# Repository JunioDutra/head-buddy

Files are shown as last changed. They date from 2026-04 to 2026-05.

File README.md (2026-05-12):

# 🤖 Desktop Buddy Robot (Raspberry Pi 3)

> Nota de estado atual (2026-04-27): o README abaixo ficou como contexto historico.
> A fonte principal do projeto atual e [AGENTS.md](AGENTS.md), e o redesign em caixa desta sessao esta em [redesign](redesign).
> A imagem [montagem.png](montagem.png) agora reflete esse redesign novo.

Projeto de um robô de mesa minimalista em formato de “cabeça”, projetado para acomodar um Raspberry Pi 3 Model B, uma tela frontal e um powerbank removível, com foco em simplicidade, modularidade e facilidade de montagem.

---

# 🎯 Propósito do Projeto

Este projeto tem como objetivo criar um **robô de mesa funcional e personalizável**, que pode ser utilizado como:

* Assistente local (LLM, automação, dashboards)
* Interface visual com tela frontal
* Dispositivo IoT ou monitoramento
* Objeto decorativo interativo

O design prioriza:

* 🧱 Estrutura simples (fácil de imprimir)
* 🔧 Montagem intuitiva
* 🔋 Manutenção rápida (bateria removível)
* 🧠 Compatibilidade com Raspberry Pi 3 Model B
* 🖥️ Integração com display frontal
* 🧵 Organização interna de cabos

---

# ⚙️ Premissas Técnicas

## 📏 Unidades e Modelagem

* Todas as dimensões são em **milímetros (mm)**
* Escala real **1:1**
* Modelagem feita no **Blender**
* Exportação em **STL**

## 🖨️ Impressão 3D

* Impressora alvo: **Creality Ender 3 V3 SE**
* Material recomendado: **PLA**
* Espessura de parede: **2 a 3 mm**
* Tolerâncias:

  * encaixes: **0.3 a 0.5 mm**
  * partes móveis: **0.5 a 1 mm**

---

# 📦 Componentes Utilizados

## 🧠 Raspberry Pi 3 Model B

* Dimensões: **85 x 56 mm**
* Furos:

  * 58 mm (horizontal)
  * 49 mm (vertical)
  * diâmetro: ~2.7 mm (M2.5)

## 🖥️ Tela

* Tipo: **2.42" OLED I2C** (modelo: 2.420LED-IIC VER:1.1)
* Driver: **SSD1309**
* Referência pública equivalente: **Waveshare 2.42inch OLED Module** para envelope e área visível, não para substituir a furação da placa real
* Resolução: **128 × 64 pixels**
* PCB (módulo): **61.5 × 39.5 mm**
* Área visível do display: **55.01 × 27.49 mm**
* Tamanho do pixel: 0.4 × 0.4 mm
* Interface: **I2C** (4 pinos: VCC, GND, SDA, SCL)
* Tensão: 3.3V / 5V
* Possui:

  * PCB maior que área visível
  * 4 furos circulares de fixação nos cantos da PCB real 2.420LED-IIC VER:1.1
  * a geometria de furação deve seguir a placa real ou foto medida da própria placa
  * não assumir pinos de encaixe como solução de montagem

## 🔋 Powerbank

* Tipo: USB padrão
* Dimensões variáveis (medir manualmente)
* Deve ser **removível facilmente**

---

# 🧱 Arquitetura do Robô

O design segue uma estrutura em camadas:

```
[ FRENTE ]
  → Tela

[ MEIO ]
  → Raspberry Pi

[ FUNDO / BASE ]
  → Powerbank (removível)
```

Benefícios:

* Organização interna
* Melhor ventilação
* Facilidade de montagem
* Acesso rápido à bateria

---

# 🧩 Peças do Projeto

O modelo é dividido nas seguintes partes:

1. Casca externa (estrutura principal)
2. Chassi interno
3. Suporte do Raspberry Pi
4. Suporte da tela
5. Berço do powerbank
6. Tampa traseira
7. Guias de cabos
8. Peça de teste de tolerância

---

# 📁 Estrutura de Saída

Cada peça deve ser exportada como:

```
/stl/
  ├── 01_shell.stl
  ├── 02_internal_chassis.stl
  ├── 03_raspberry_mount.stl
  ├── 04_screen_mount.stl
  ├── 05_powerbank_holder.stl
  ├── 06_back_cover.stl
  ├── 07_cable_guides.stl
  ├── 08_tolerance_test.stl
```

---

# 🧠 Workflow de Desenvolvimento

1. Criar peça no Blender
2. Validar dimensões (painel N)
3. Exportar STL
4. Abrir no slicer (Cura / Prusa)
5. Validar escala
6. Imprimir peça de teste
7. Ajustar tolerâncias
8. Imprimir versão final

---

# ⚠️ Boas Práticas

* Sempre modelar com folga (não justo)
* Nunca confiar “no olho”
* Validar encaixes antes de imprimir tudo
* Priorizar acesso fácil à manutenção
* Planejar cabos desde o início

---

# Imagem da montagem
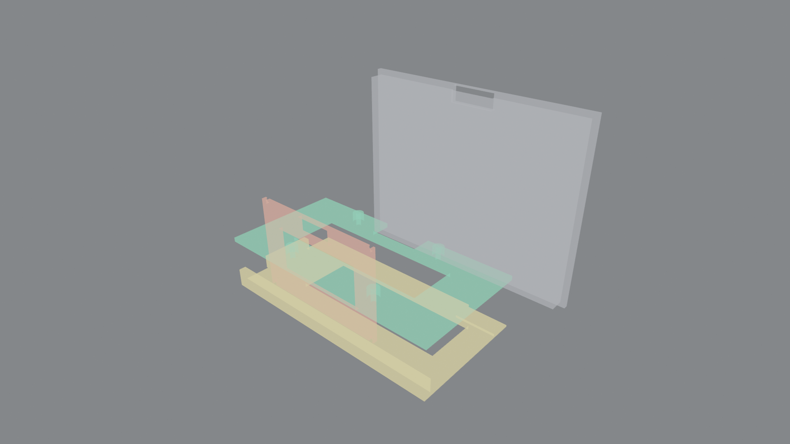
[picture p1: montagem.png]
Imagem do robô montado


---

# 🚀 PROMPTS DE MODELAGEM (ORDEM DE EXECUÇÃO)

## 🔹 0. Prompt Base (usar antes de todos)

```text
Crie uma peça técnica para impressão 3D e também uma imagem ortográfica/industrial do mesmo objeto. 
Use unidades em milímetros, escala real 1:1, precisão mecânica, tolerâncias de impressão 3D e aparência limpa de CAD.
A peça faz parte de um robô de mesa em formato de cabeça quadrada, simples e modular, fácil de montar e desmontar.
Priorize:
- encaixes simples
- manutenção fácil
- passagem organizada de cabos
- fixação segura dos componentes
- paredes com 2 a 3 mm de espessura
- folgas funcionais de 0,3 a 0,5 mm para encaixes impressos em 3D
Não invente proporções artísticas. Respeite medidas reais.
```

---

## 🔹 1. Casca externa

```text
Crie a casca externa de uma cabeça quadrada para robô de mesa, com design minimalista e funcional.

Dimensões externas alvo:
- largura: 120 mm
- altura: 100 mm
- profundidade: 80 mm

Abertura frontal para tela 2.42" OLED:
- abertura: 57 x 29.5 mm (área visível 55x27.5mm + 1mm margem)
- centralizada na frente, a 50mm de altura

Requisitos:
- frente com abertura central para a tela 2.42" OLED
- moldura frontal com espessura visível de 3 a 5 mm
- cantos levemente arredondados (bevel 5mm, 4 segmentos)
- traseira com tampa removível (abertura 110x90mm)
- base estável para ficar sobre mesa
- espaço interno suficiente para Raspberry Pi 3, tela e powerbank
- ventilação discreta nas laterais (5 slots por lado, 2x25mm)
- 4 postes internos de fixação (raio 3mm, altura 5mm)
- manter aparência de “buddy robot”, sem detalhes excessivos

Importante:
- gerar a peça como corpo oco
- prever espessura de parede de 2 a 3 mm
- prever pontos de fixação internos para as demais peças
- não incluir eletrônica modelada, só a estrutura externa
```

---

## 🔹 2. Chassi interno

```text
Crie o chassi interno principal para um robô de mesa em formato de cabeça quadrada.

Função da peça:
- sustentar a tela na frente
- sustentar o Raspberry Pi 3 no meio
- sustentar um powerbank removível na parte traseira ou inferior
- organizar o volume interno em camadas

Requisitos:
- estrutura interna modular
- canais para cabos com pelo menos 5 mm de largura útil
- folga mínima de 1 mm entre componentes e paredes
- divisões internas para separar área da tela, área da placa e área da bateria
- permitir montagem por etapas
- deixar acesso fácil às portas laterais/traseiras do Raspberry
- incluir pontos de apoio para a tampa traseira

Formato:
- peça única ou conjunto simples de suportes interligados
- geometria sólida, sem partes frágeis
- compatível com impressão 3D sem suportes complexos
```

---

## 🔹 3. Suporte Raspberry Pi

```text
Crie um suporte interno específico para Raspberry Pi 3 Model B, em peça separada, com fixação por parafusos.

Medidas obrigatórias da placa:
- placa: 85 mm x 56 mm
- padrão de fixação: 58 mm x 49 mm entre centros dos furos
- cantos da placa com raio aproximado de 3,0 mm
- usar furos de fixação com folga para parafuso M2.5, com diâmetro de passagem em torno de 2,7 mm

Requisitos do suporte:
- 4 standoffs alinhados com os furos oficiais do Raspberry Pi 3 Model B
- altura dos standoffs: 6 mm
- base reforçada para não dobrar
- manter a placa suspensa para passagem de cabos
- deixar as portas USB, Ethernet, HDMI e alimentação acessíveis por uma lateral ou traseira
- tolerância de montagem de 0,3 a 0,5 mm
- bordas arredondadas para facilitar impressão e montagem

Entregue a peça em escala real, pronta para encaixar no interior do robô.
```

---

## 🔹 4. Suporte da tela

```text
Crie a moldura frontal interna e o suporte da tela do robô de mesa.

Tela: 2.42" OLED I2C (SSD1309, 128x64px)
- largura da PCB: 61.5 mm
- altura da PCB: 39.5 mm
- área visível: 55.01 mm x 27.49 mm
- interface: I2C (4 pinos: VCC, GND, SDA, SCL)
- padrão de furos: ~57.5 mm x 35.5 mm (centro a centro)
- diâmetro dos furos: 2.7 mm (M2.5)

Requisitos:
- criar uma janela frontal alinhada exatamente com a área visível
- deixar a PCB da tela escondida atrás da frente
- prever pelo menos 10 mm de espaço atrás da tela para cabo e eletrônica
- incluir 4 pontos de fixação ou um encaixe por pressão controlado
- borda de apoio interna para a tela não cair para a frente
- tolerância de 0,3 a 0,5 mm nos encaixes
- moldura frontal simples, limpa e fácil de imprimir

A peça deve servir tanto como suporte técnico quanto como moldura estética frontal.
```

---

## 🔹 5. Berço do powerbank

```text
Crie um berço removível para prender um powerbank dentro de uma cabeça quadrada de robô de mesa.

Medidas reais do powerbank:
- largura: [LARGURA_POWERBANK] mm
- altura: [ALTURA_POWERBANK] mm
- profundidade: [PROFUNDIDADE_POWERBANK] mm

Requisitos:
- a peça deve permitir remover o powerbank com facilidade, sem desmontar o robô inteiro
- usar encaixe por trilho, berço lateral ou trava simples por pressão
- não usar parafusos no powerbank, para permitir retirada rápida
- deixar folga de 0,5 a 1,0 mm para inserção manual
- prever passagem para cabo de energia sem esmagar o conector
- garantir que o powerbank fique firme durante o uso
- base com apoio plano e lateral com retenção suave
- evitar cantos muito fechados

A peça deve ser simples, robusta e pensada para acesso frequente.
```

---

## 🔹 6. Tampa traseira

```text
Crie a tampa traseira de manutenção para um robô de mesa em formato de cabeça quadrada.

Requisitos:
- abertura fácil para acessar o powerbank, Raspberry Pi e cabos
- fixação simples por snap-fit ou por parafusos M3
- remoção manual sem ferramentas complexas
- encaixe alinhado com a casca externa
- borda de apoio com tolerância de 0,3 a 0,5 mm
- incluir travas ou linguetas suficientes para não abrir sozinha
- manter aparência limpa por fora
- prever ventilação, se necessário, sem comprometer a rigidez

A peça deve ser funcional, discreta e fácil de imprimir.
```

---

## 🔹 7. Guias de cabos

```text
Crie um conjunto de guias internos para cabos dentro de um robô de mesa com Raspberry Pi 3, tela frontal e powerbank removível.

Requisitos:
- canais com largura útil mínima de 5 mm
- curvas suaves, sem dobras apertadas
- separação entre cabos de energia e cabos de sinal quando possível
- clipes ou presilhas opcionais para prender fios
- manter 10 mm de folga atrás da tela
- não bloquear ventilação nem acesso às portas do Raspberry
- guias simples, integradas ao chassi, fáceis de imprimir

A peça deve organizar os fios sem aumentar demais o volume interno.
```

---

## 🔹 8. Peça de teste

```text
Crie uma peça de teste pequena para validar tolerâncias de encaixe antes do modelo final.

Requisitos:
- testar folgas de 0,2 mm, 0,3 mm, 0,4 mm e 0,5 mm
- incluir pequenos encaixes tipo trava, canal e pino
- usar espessura de parede igual à peça final
- servir para validar a impressora e o material
- geometria simples, compacta e rápida de imprimir

A peça deve ajudar a confirmar o ajuste dos encaixes antes de produzir o robô completo.
```

---

# 🧠 Considerações Finais

Este projeto foi pensado para ser:

* Modular
* Iterativo
* Customizável

Não existe uma única versão final — a ideia é evoluir o design conforme testes reais.

---

# � Histórico de Alterações

## v2 — Correção da tela (2.42" OLED I2C)

As peças originais foram modeladas com dimensões de um display 3.5" SPI (PCB 86×56mm).
Após testes de impressão, identificou-se que a tela real é um **2.42" OLED I2C** (PCB 61.5×39.5mm).

Peças reconstruídas:
- **01_shell**: abertura frontal reduzida de 70×50mm para **57×29.5mm**
- **02_internal_chassis**: zona da tela reduzida de 15mm para **12mm** de profundidade
- **04_screen_mount**: totalmente recriado para PCB 61.5×39.5mm, janela 56×28.5mm, slot para cabo I2C, orientação flat para impressão sem suportes. A furação final deve seguir a placa real da OLED 2.420LED-IIC VER:1.1, com **4 furos circulares de canto**

Dimensões confirmadas por referência pública equivalente Waveshare 2.42" OLED Module (SSD1309):
- Módulo: 61.5 × 39.5 mm
- Área visível: 55.01 × 27.49 mm
- Pixel: 0.4 × 0.4 mm
- Resolução: 128 × 64

---

# 💡 Próximos Passos

* Integrar áudio (speaker + mic)
* Criar versão com ventilação ativa
* Evoluir design externo (personalidade do robô)

---

# 👾 Filosofia do Projeto

> Primeiro funcional. Depois bonito. Sempre simples.

---

Boa sorte com o build 🚀

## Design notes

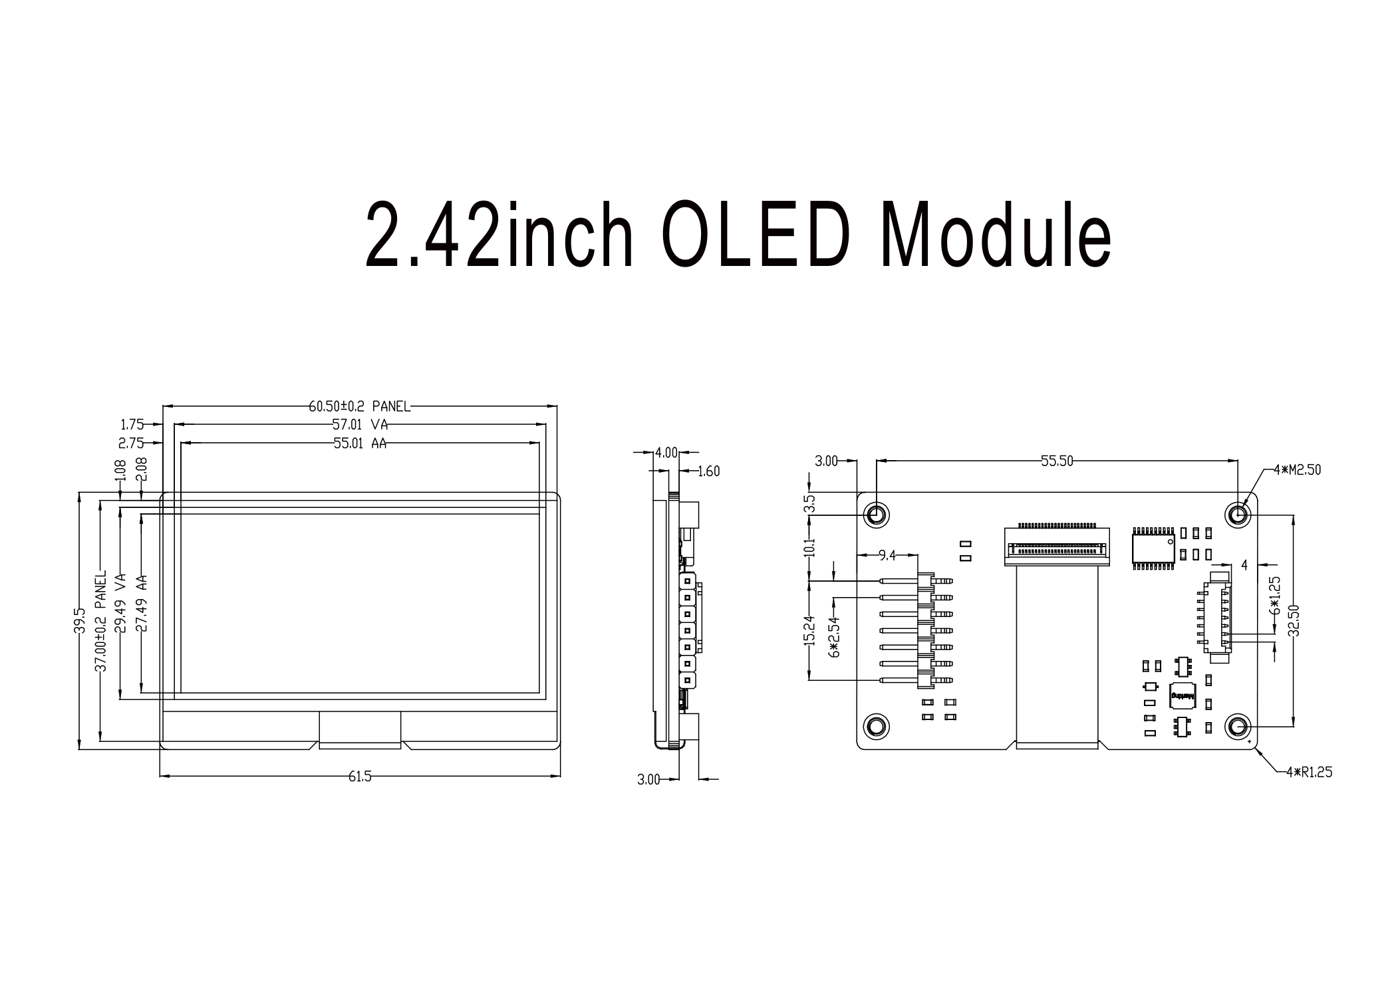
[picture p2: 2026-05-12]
design/tmp_oled_ref_page1.png

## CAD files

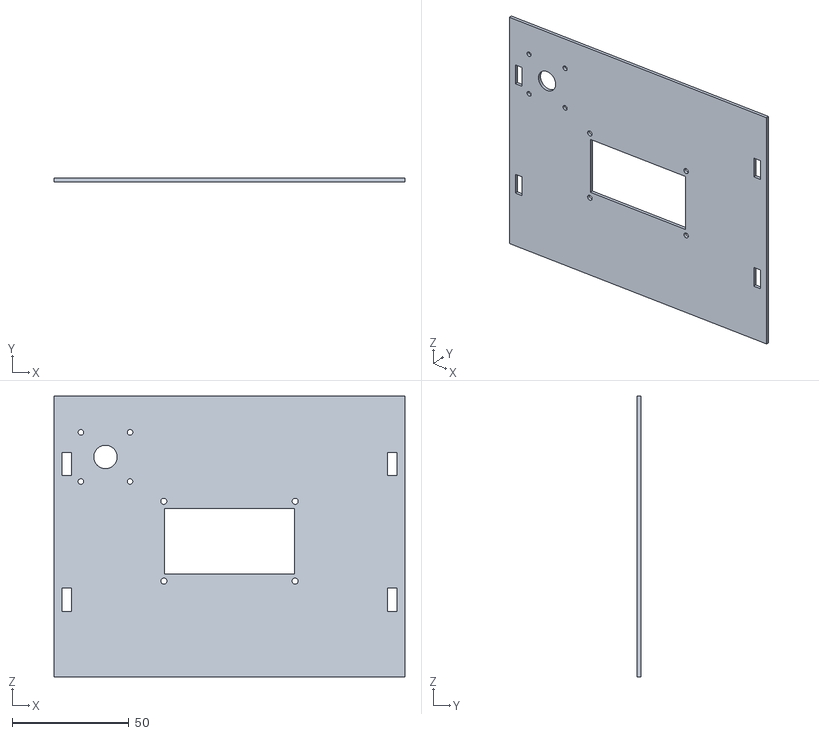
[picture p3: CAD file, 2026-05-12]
design/stl/rd_front_panel_v3.stl
150.0 x 1.50 x 120.0

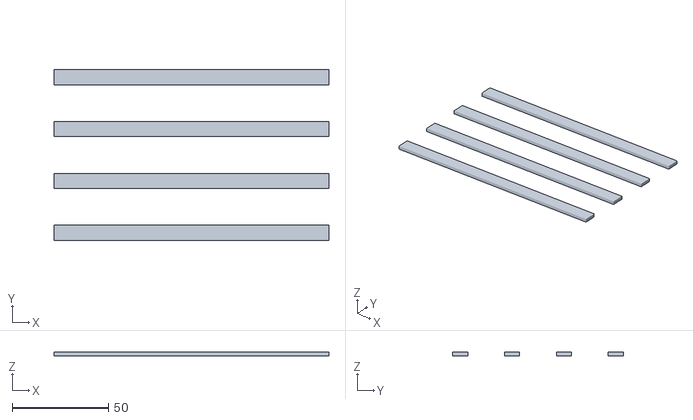
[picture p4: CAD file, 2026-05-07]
design/stl/rd_support_slat_base_v1.stl
143.0 x 89.0 x 2.13

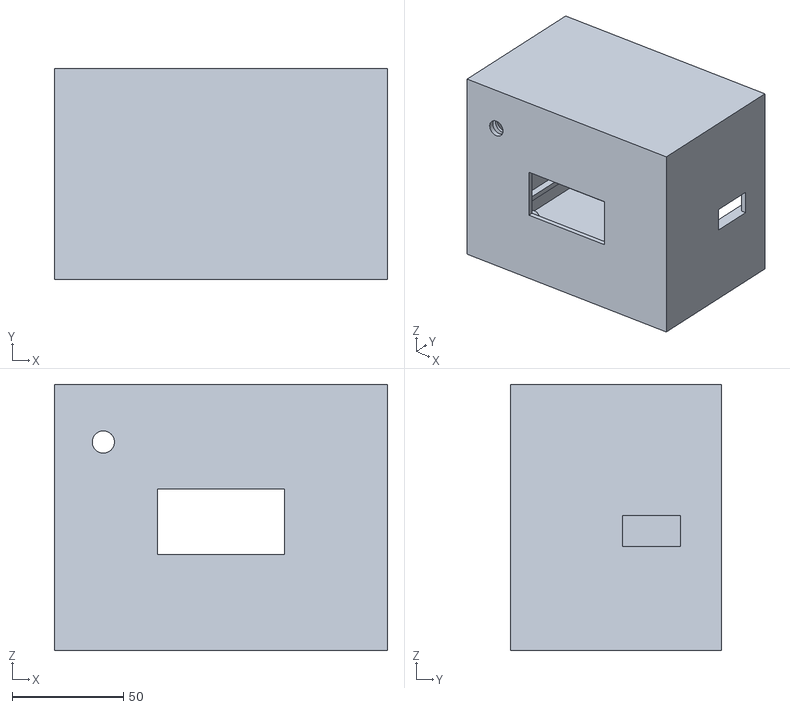
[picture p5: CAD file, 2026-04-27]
design/stl/rd_shell_v1.stl
150.0 x 95.0 x 120.0

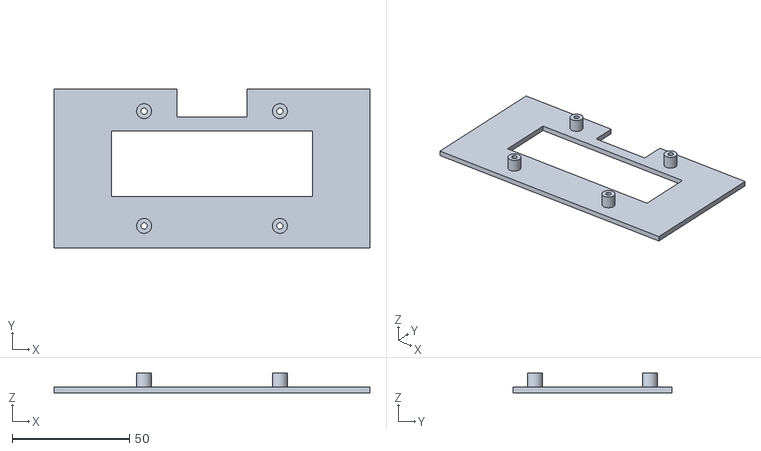
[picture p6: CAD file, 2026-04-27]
design/stl/rd_rpi_support_v1.stl
135.0 x 68.0 x 8.50

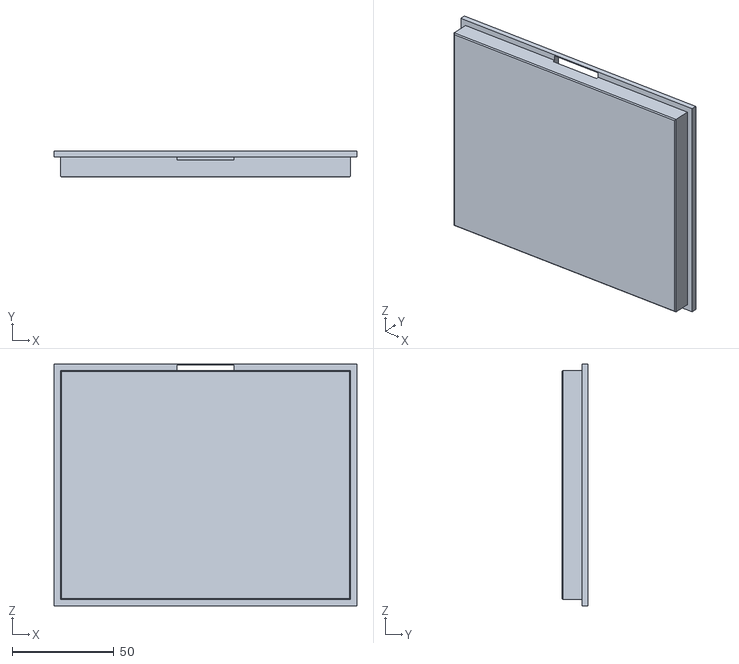
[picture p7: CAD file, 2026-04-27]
design/stl/rd_back_cover_v1.stl
149.0 x 13.0 x 119.0

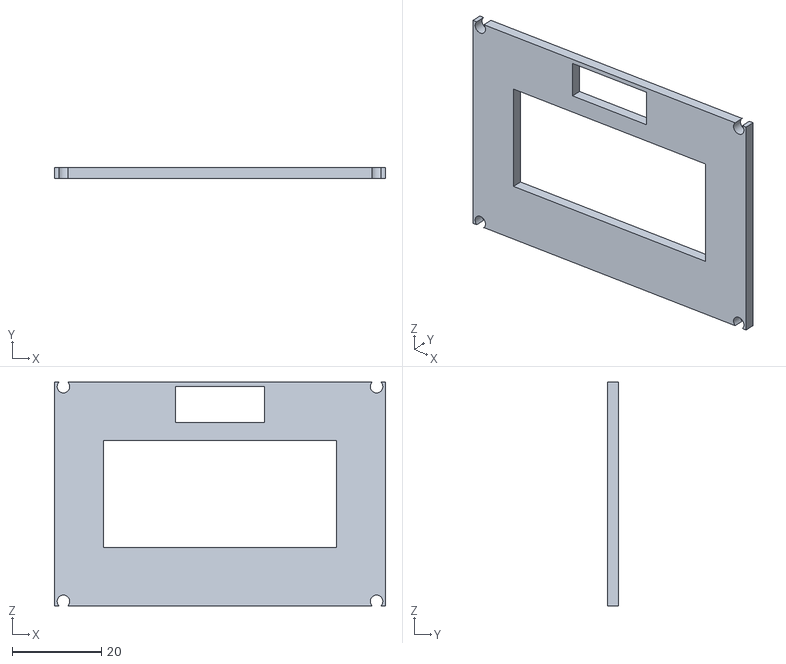
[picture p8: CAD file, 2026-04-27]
design/stl/rd_oled_retainer_v1.stl
74.0 x 2.40 x 50.0

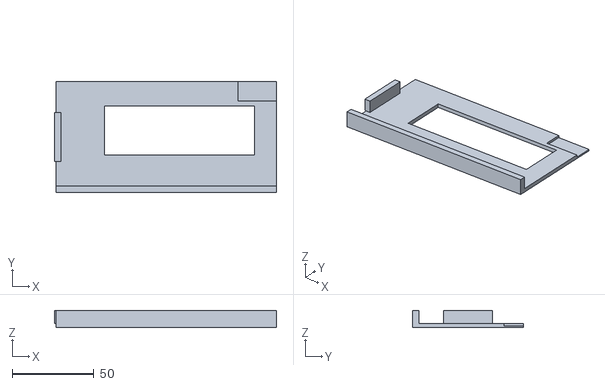
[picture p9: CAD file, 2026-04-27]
design/stl/rd_power_shelf_v1.stl
136.0 x 68.0 x 10.5

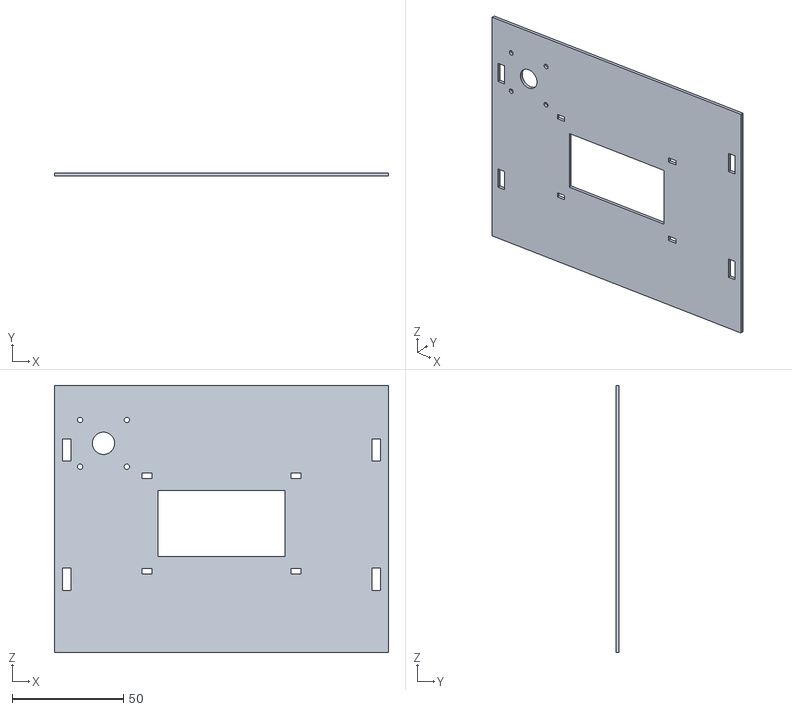
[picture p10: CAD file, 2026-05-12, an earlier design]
design/stl/rd_front_panel_v2.stl
150.0 x 1.50 x 120.0

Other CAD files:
design/stl/rd_front_panel_v1.stl
design/box_front_panel_mcp_v1.blend
design/box_front_panel_mcp_v2.blend
design/box_front_panel_mcp_v3.blend
design/box_redesign_mcp_v1.blend
home.blend

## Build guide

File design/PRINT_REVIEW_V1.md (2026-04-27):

# Print Review V1

Checkpoint revisado em 2026-04-27 sobre o redesign salvo em box_redesign_mcp_v1.blend.

## Tampa traseira

- A abertura interna traseira da shell esta em 144.0 x 114.0 mm.
- O plug da tampa esta em 142.8 x 112.8 mm.
- Folga nominal do plug: 0.6 mm por lado.
- Foi adicionado um chanfro de entrada de 0.6 mm no bordo do plug para reduzir travamento por elephant foot.
- Recomendacao de primeiro print: imprimir a tampa deitada, com a face externa na mesa e o plug voltado para cima.

## Retentor da OLED

- O retentor esta coerente com os quatro posts frontais da shell e nao precisou ajuste de geometria neste passe.
- Como os furos pequenos tendem a fechar no PLA, trate-os como furos piloto no primeiro print.
- Se usar parafuso passante, reabra manualmente os furos para a medida final depois do print.

## Fixacao da camera

- A camera continua com logica correta de fixacao integrada na shell.
- Para o primeiro prototipo, mantenha a ideia de furo piloto e so leve ao diametro final depois do print, se necessario.
- Isso evita ampliar demais a folga antes de validar a camera real e o comportamento da impressora.

## Leitura pratica

- A revisao atual ja esta boa para um primeiro dry-fit funcional.
- O ponto mais sensivel continua sendo a tampa traseira, mas agora ela esta dentro da faixa de folga desejada e com entrada guiada.
- Se houver aperto no primeiro print, ajuste seguinte deve ser pequeno: +0.2 mm total no plug, nao uma reformulacao da peça.

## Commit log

2026-04-05 Refactor code structure for improved readability and maintainability
    [01_shell.stl, 02_internal_chassis.stl, 03_raspberry_mount.stl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]
2026-04-05 Add project guide and hardware specifications for Desktop Buddy Robot
    [home.blend]
2026-05-12 Add initial design files for 2.42inch OLED Module
    - Added tmp_oled_ref.pdf containing design specifications.
    - Added tmp_oled_ref_page1.png as a visual reference for the OLED module.
    [box_front_panel_mcp_v1.blend, box_front_panel_mcp_v2.blend, box_front_panel_mcp_v3.blend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]
